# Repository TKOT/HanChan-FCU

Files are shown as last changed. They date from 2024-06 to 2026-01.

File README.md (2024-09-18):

# HanChan-FCU（寒蝉FCU）

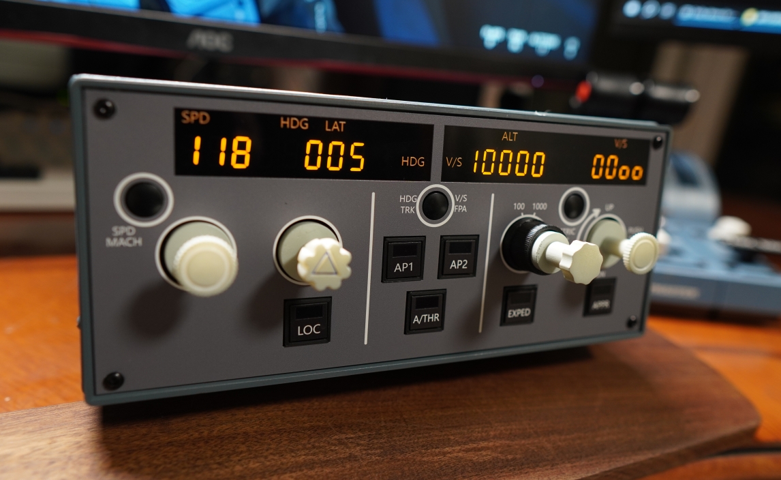
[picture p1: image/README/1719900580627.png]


## 项目简介

HanChan-FCU（寒蝉FCU）这个是基于MobiFlight固件与Arduino mega2560开发板自制的空客Airbus A320的FCU（飞行控制单元），推拉机械结构参考使用了用户@Santi Luib III。

基于mobiflight固件，所以此项目的FCU能支持配置到市面上几乎所有主流的模拟飞行平台和机型，且硬件维护成本较低，采用金属外壳。

本项目是起因是重新游玩“微软模拟飞行2020”，当时市面上无售价合适性价比较高的空客FCU产品（现在已有几个不错产品），而且中文互联网也没有人分享DIY方案。所以就想到要自己DIY一个FCU产品。

整个项目是本人一个人用业余时间完成的，修改迭代了上百个小版本，无偿分享给飞友。

本人做视频与分享知识的一个目的也是希望提升中文社区的一个技术氛围。能增加中文互联网的开源整体环境，每个人互帮互助。

希望大家之后也能发布相关学习经验 来提高中文网上社区环境。

项目整体介绍视频：[点击此文字](https://www.bilibili.com/video/BV154421D7D3/)

硬件制作教程视频：[点击此文字](https://www.bilibili.com/video/BV18z421q7wh)

讨论群：923213555

## 版权控制

本项目禁止其他任何商业行为，**仅供飞友个人DIY使用。**

如有发现有其他商业使用的行为（包括不限于闲鱼淘宝等），将直接闭源，不再更新。

在粉丝建议下加入，如果非要商用：“商用者即同意条款：将营业额60%作为技术费用付给开源作者本人。”

## 第一次使用教程

### 一、刷入固件教程：

#### 1.按图所示选择先选择 Arduino Mega2560 刷入底层固件。

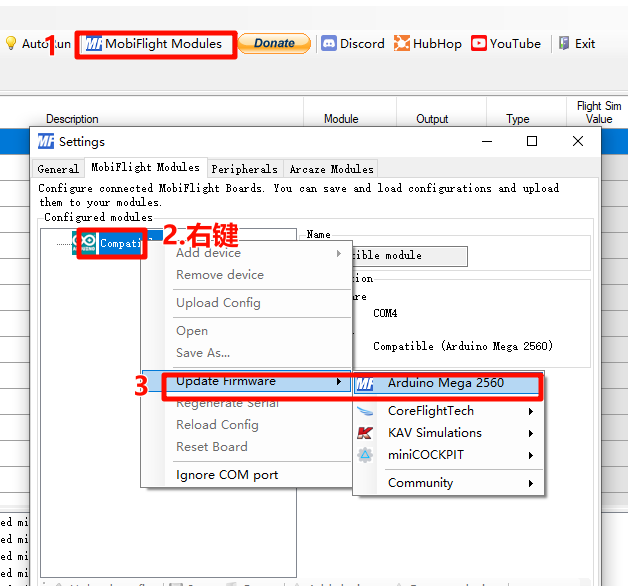
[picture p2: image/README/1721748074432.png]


#### 2.载入固件配置：（固件配置名称 例：HanChan-V1-2-3.mfmc）

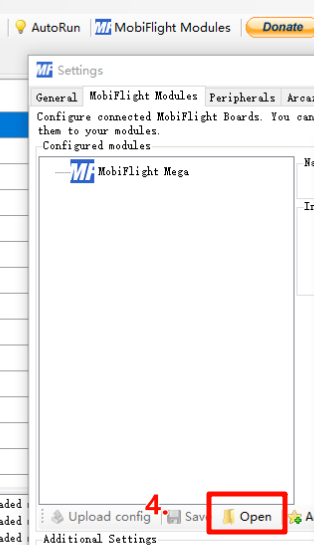
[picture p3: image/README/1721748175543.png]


### 二、加载mobi配置步骤：

1. **先插入FCU到电脑。**
2. **打开mobi软件并 打开配置**。配置名例：**V1.2.3fenixA320.mcc**

   

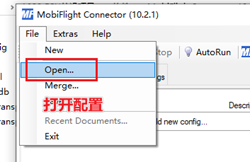
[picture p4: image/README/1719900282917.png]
   

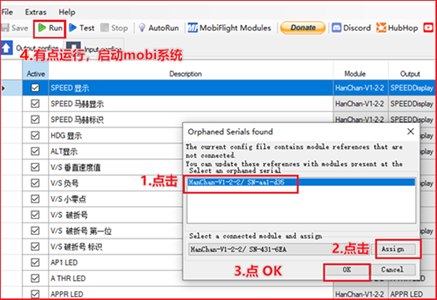
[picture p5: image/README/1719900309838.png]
   
3. **结束配置，以后插入FCU使用点击Run 就可以直接使用FPU了。**

## 项目更新

V1.2.3：
显示模块重置，配置做修改。

V1.2.2：
1.重写了配置文件，完善了功能。
2.面板尺寸修改。减少与金属机箱缝隙。
3.打印面板参考真机样式，小改。

V1.2.1：
1.推拉结构间隙调整，提高手感减小矿量。
2.圆形按钮 卡槽加高深度。按钮突出更合理点。
2.面板UV打印部分做了小修改。

V1.2.0：
1.升级了上面三个圆形按钮的元件选型，继续靠近真机细节。
2.更改了面板布局，整个外面，面板UV打印部分重置重新绘制过了。
3. 3D打印的主体面板，设置设计升级了定位孔，减少胶水粘结部分，改为螺丝连接，更加紧固了。
4.拖拉结构的定位孔进行了细调，用来配合主体面板。

## 支持

如果帮助到大家，欢迎大家捐赠和购买我的配件合集来支持项目的更新与迭代。

闲鱼 直接搜 “寒蝉FCU”或者 “寒蝉唱游”就可以了。

如果有需要配件打包的可以到我闲鱼去看下，先上架了了一个预定包。预定包中的配件除了有各种标准电子原件外，还包涵了市面上没有的各种定制件，包含了12位数码管等，而且有部分喷漆改色打磨服务，还有贴纸面板等。主要是简化了大家的定制的精力。

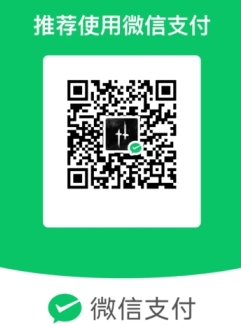
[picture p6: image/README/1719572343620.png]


## 感谢

感谢前期支持迭代，帮忙内测的群友。

@fullofghost   感谢贡献

@紫聪聪         感谢贡献

@Santi Luib III  	模型与机械结构

@L7          		A320真机飞行员 提供真机照片与细节

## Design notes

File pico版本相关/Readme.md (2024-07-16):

# 注意：
1. 买看着像的PICO就行
1. 74HC165按需来，优先小标号（U1），可以根据需要只焊接一个或者两个，不能空过1焊23。74HC595同理。
1. 74HC595配套限流电阻选了220R，可以根据自己选择喜好来换。
1. 增加了亮度控制在14引脚，配置请启用PWM，用于控制所有led亮度，默认不配置就是最大亮度，选配。

# 使用相关
1. 按钮顺序其实建议随便焊接，软件里面挨个调一次比看着配置焊接要方便，灯同理。板子模块配置文件可以加载Pico.mfmc。
2. H1,2,3为按钮
3. H8位编码器左右
4. H9 H10为LED灯
5. H5 H6为74HC165与74HC595与MCU的引脚，用于不会在板子上焊芯片的同学飞线用，不过74HC165本身不带上下拉电阻，不确定是否有问题。
6. H7是LED数码管模块输出引脚。
7. 面板增加了很多LED的位置，用于增加切换显示灯，可以一对一焊接，也可以一组焊在一起。

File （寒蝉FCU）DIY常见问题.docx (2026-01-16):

# 寒蝉FCU 制作DIY常见问题

1. 数码管乱码。

大概率是杜邦线稳定性太差，接触不良导致。可以换更好的硅胶杜邦线，或者直接焊接。

2. 无12位数码管。

可以使用两个8位代替，其中一个去掉四位数码管即可。高度可用排针调整。

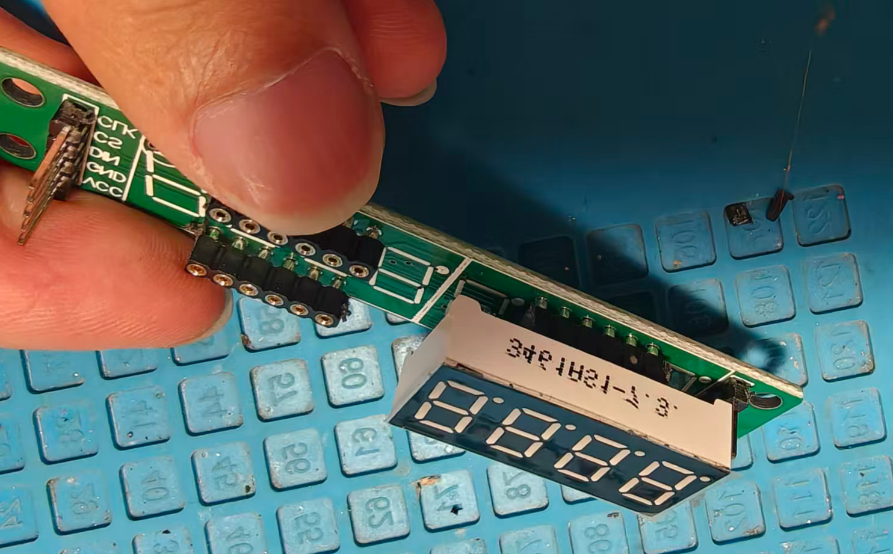
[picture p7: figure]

3. 如何方便的调整数码管模块的方位针脚。

加热焊盘顶出即可。

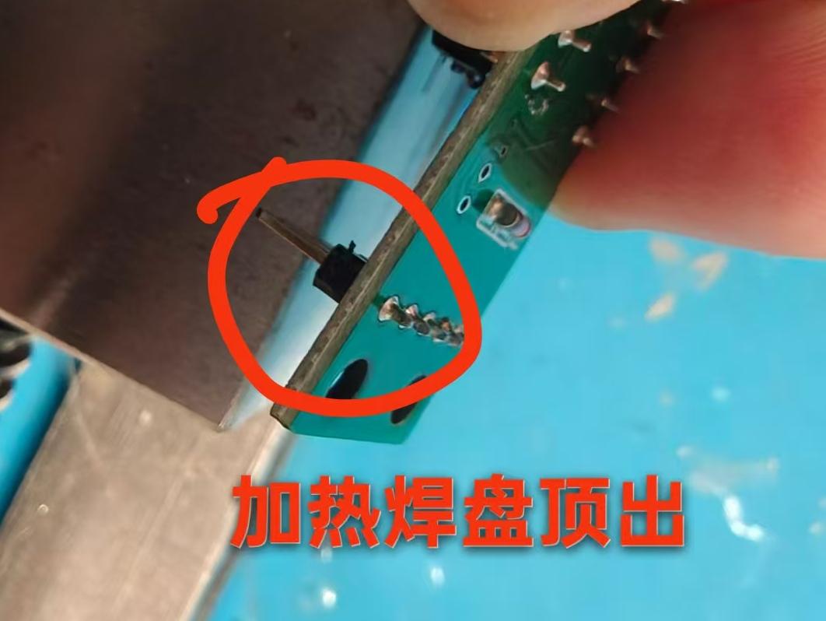
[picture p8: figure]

4. 如何方便调试FCU功能是否正常。

设置中开启log即可

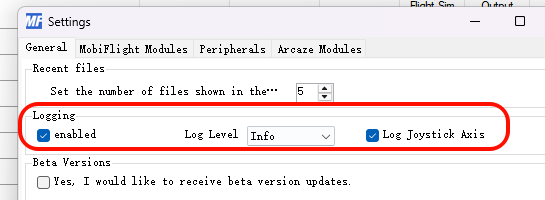
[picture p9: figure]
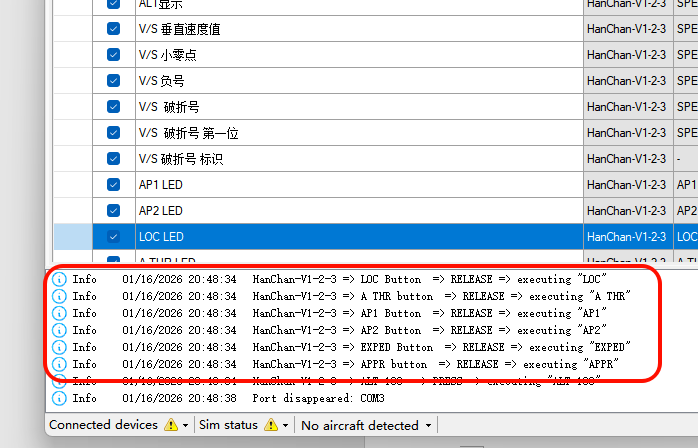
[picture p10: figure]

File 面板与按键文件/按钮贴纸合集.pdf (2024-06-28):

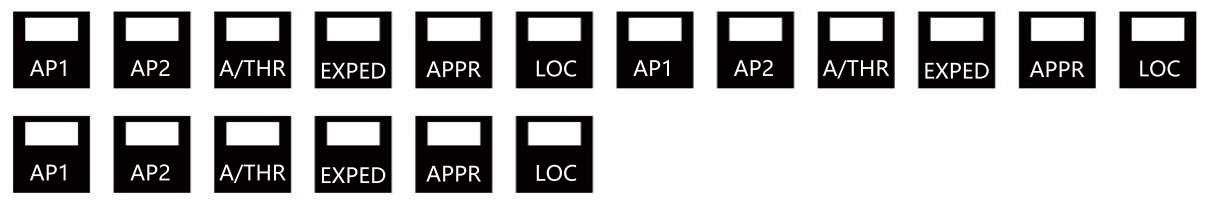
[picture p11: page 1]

AP1 | AP2 | A/THR EXPED | APPR | LOC | AP1 | AP2 | A/THR EXPED | APPR | LOC
AP1 | AP2 | A/THR EXPED | APPR | LOC

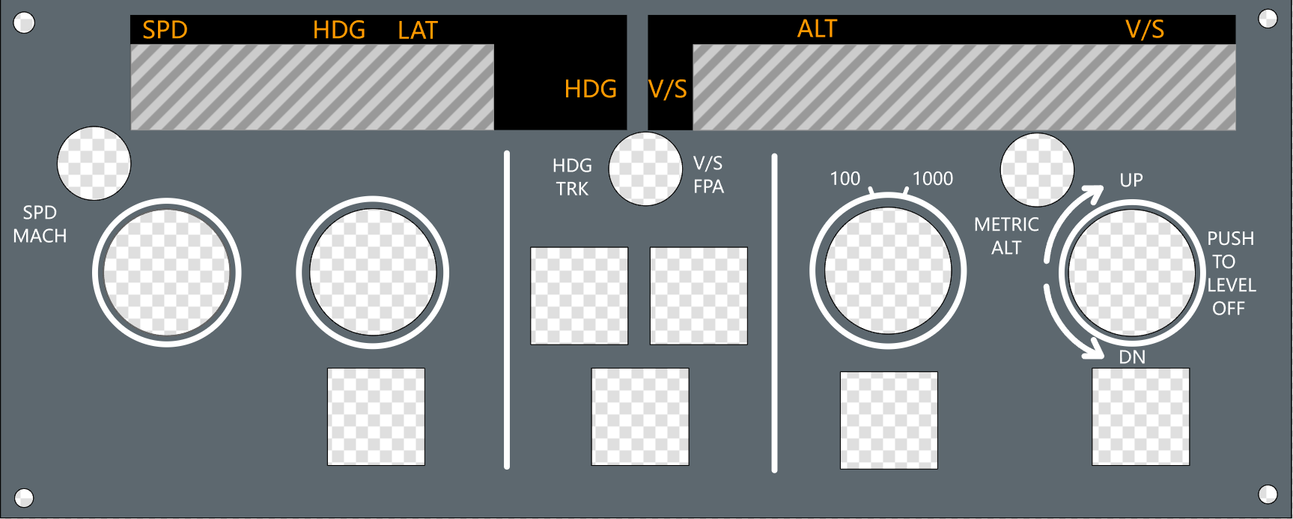
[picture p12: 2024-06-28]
面板与按键文件/前面板.webp

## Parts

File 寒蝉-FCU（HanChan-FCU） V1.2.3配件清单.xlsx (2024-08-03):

寒蝉-FCU（HanChan-FCU） V1.2.3配件清单
视频教程 |  | https://www.bilibili.com/video/BV18z421q7wh
名称 | 规格 | 数量 | 备注
灯光按钮3D打印件 | 灯光上盖 | 6
 | 内壳 | 6
 | 外壳 | 6
高度旋钮3D打印件 | 100-1000 选择 | 1
 | 高度-面板链接件 | 1
 | 高度旋钮外壳 | 1
 | 连杆 | 1
 | 钮子开关座 | 1
 | 钮子拨杆 | 1
其他3D打印件 | 推拉内壳 | 4
 | 推拉外壳 v16 | 3
 | 主板支架 v3 | 1
 | 主面板 | 1 | 219*88mm
 | 航向按钮 圆形版本 | 1
 | 速度按钮 圆形版本 | 2
 | 速度按钮半圆 | 2 | 可选
 | 航向按钮半圆 | 1 | 可选
 | 高度选择旋钮 | 1
按钮 | 12*12*7.3mm方头 | 7
 | 3*6*4.3MM立式插脚白色黑色2脚 | 6
LED发光管 | 3mm绿色 | 6
数码管模块 | 8位数码管模块max7219 led八位 | 3 | 需要自己拆换
杜邦线 | 母对公、母对母等 | 几十 | 粗估
编码器 | ec11 20mm (https://item.taobao.com/item.htm?id=600216770759&_u=r41dfih1381) | 4
钮子开关 | mts-102 | 1
电阻 | 2.2k 直插 | 6
按钮帽 | 轻触开关帽，圆形直径10mm | 3 | 配12*12*7.3mm方头
主板 | Arduino mega2560 | 1
机箱 | 单面配合主面板尺寸219*88mm即可 | 1
灯光印刷贴纸或面板 | 开源定制 | 6
主面板 贴纸或面板 | 开源定制 | 1
螺丝 | M3*8 | 16 | 建议不同长度的配点备用
 | M3*12 | 2
 | M3 螺丝 螺母一套 | 2 | 固定主板

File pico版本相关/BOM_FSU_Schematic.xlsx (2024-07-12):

No. | Quantity | Comment | Designator | Footprint | Value | Manufacturer Part | Manufacturer | Supplier Part | Supplier
1 | 1 | Btn0 | H1 | HDR-TH_16P-P2.54-V-M-R2-C8-S2.54 |  |  |  | C68234
2 | 1 | Btn1 | H2 | HDR-TH_16P-P2.54-V-M-R2-C8-S2.54 |  |  |  | C68234
3 | 1 | Btn2 | H3 | HDR-TH_16P-P2.54-V-M-R2-C8-S2.54 |  |  |  | C68234
4 | 1 | HDR-M_2.54_1x16P | H4 | HDR-TH_16P-P2.54-V-M |  |  |  | C2894939
5 | 1 | LED输出 | H5 | HDR-TH_5P-P2.54-V-M |  | MTP125-1105S1 | MINTRON(明硕) | C358687 | LCSC
6 | 1 | BTN输入 | H6 | HDR-TH_5P-P2.54-V-M |  | MTP125-1105S1 | MINTRON(明硕) | C358687 | LCSC
7 | 1 | Display模块 | H7 | HDR-TH_5P-P2.54-V-M |  | MTP125-1105S1 | MINTRON(明硕) | C358687 | LCSC
8 | 1 | Encoder连接 | H8 | HDR-TH_8P-P2.54-V-F-R2-C4-S2.54-1 |  |  |  | C92271
9 | 2 | HDR-F_2.54_2x8 | H9,H10 | HDR-TH_16P-P2.54-V-F-R2-C8-S2.54-1 |  |  |  | C30734
10 | 2 | M3螺丝 | TP1,TP2 | M3螺丝
11 | 3 | 74HC165D,653 | U1,U2,U3 | SOIC-16_L9.9-W3.9-P1.27-LS6.0-BL |  | 74HC165D,653 | Nexperia(安世) | C5613 | LCSC
12 | 6 | 10K排阻-4D03 | U4,U5,U6,U7,U8,U9 | RES-ARRAY-SMD_8P-L3.2-W1.6-P0.80-BL |  | 10K排阻-4D03 |  | C9900011904 | LCSC
13 | 1 | PICO | U10 | COMM-SMD_L51.0-W21.0-P2.54_SC0916 |  | PICO | Raspberry Pi(树莓派) | C7203002 | LCSC
14 | 4 | 470Ω | U11,U13,U15,U16 | RES-ARRAY-SMD_0603-8P-L3.2-W1.6-BL | 470Ω | 4D03WGJ0471T5E | UNI-ROYAL(厚声) | C25510 | LCSC
15 | 2 | 74HC595 | U12,U14 | SOP-16_L9.9-W3.9-P1.27-LS6.0-BL |  | 74HC595 | GR(国睿) | C18164493 | LCSC

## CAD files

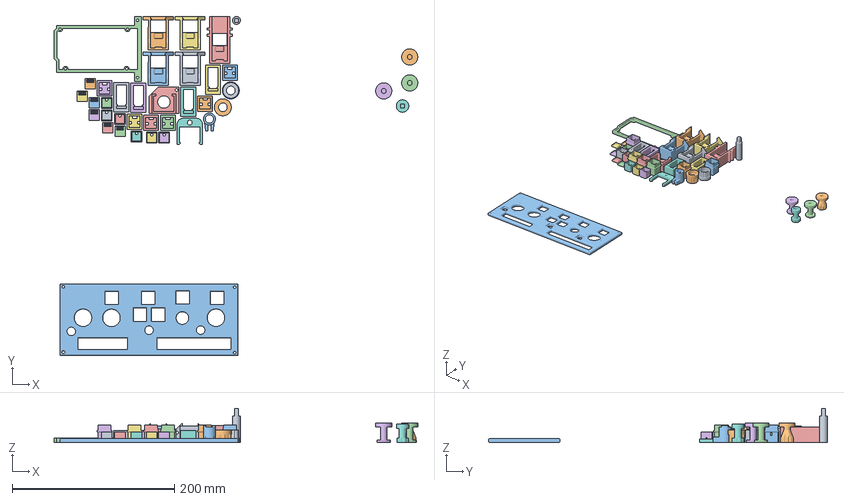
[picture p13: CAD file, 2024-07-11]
3D打印模型/all.3mf
447.9 x 417.5 x 41.9 mm
连杆.stl
航向按钮 圆形版本.stl
主面板.stl
速度按钮 圆形版本.stl x 2
高度旋钮外壳.stl
推拉外壳 v16.stl x 4
高度选择按钮.stl
主板支架 v3.stl
高度-面板链接件.stl
推拉内壳.stl x 4
外壳.stl x 6
钮子开关座.stl
100-1000 选择.stl x 2
钮子拨杆.stl
内壳.stl x 6
灯光按钮上盖 v2.stl x 6

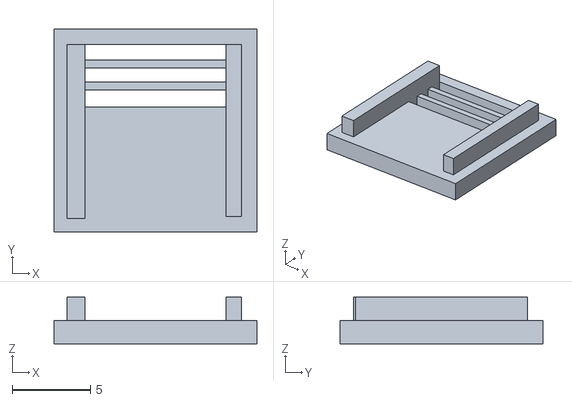
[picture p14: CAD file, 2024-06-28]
3D打印模型/灯光按钮/灯光按钮上盖 v2.stl
13.0 x 13.0 x 3.00

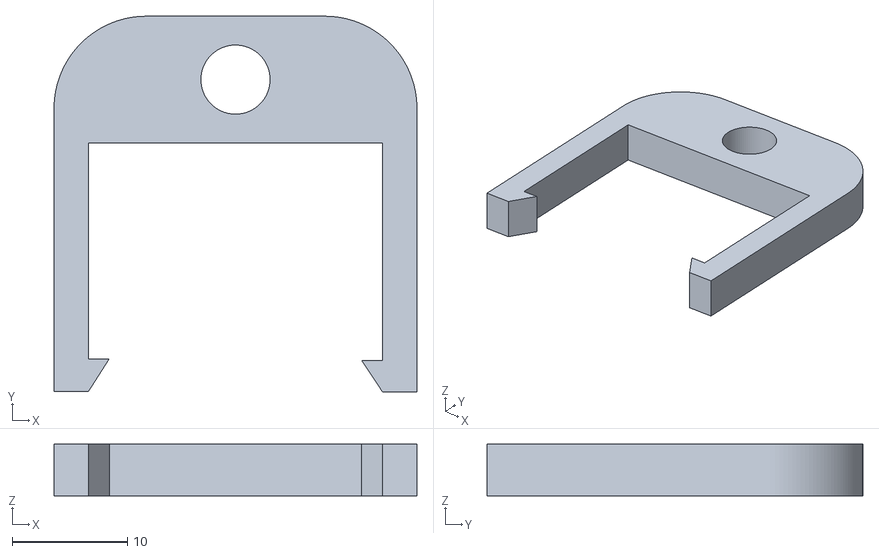
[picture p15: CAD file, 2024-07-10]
3D打印模型/高度旋钮部分/钮子开关座.stl
31.5 x 32.6 x 4.50

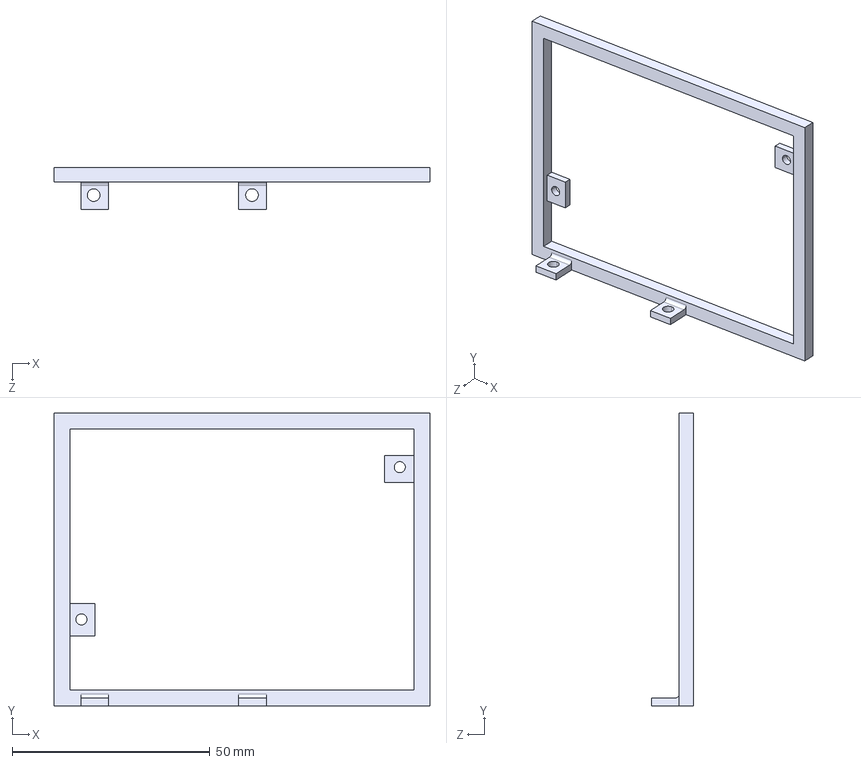
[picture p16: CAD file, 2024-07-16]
pico版本相关/托板.STEP
95.0 x 74.0 x 10.6 mm

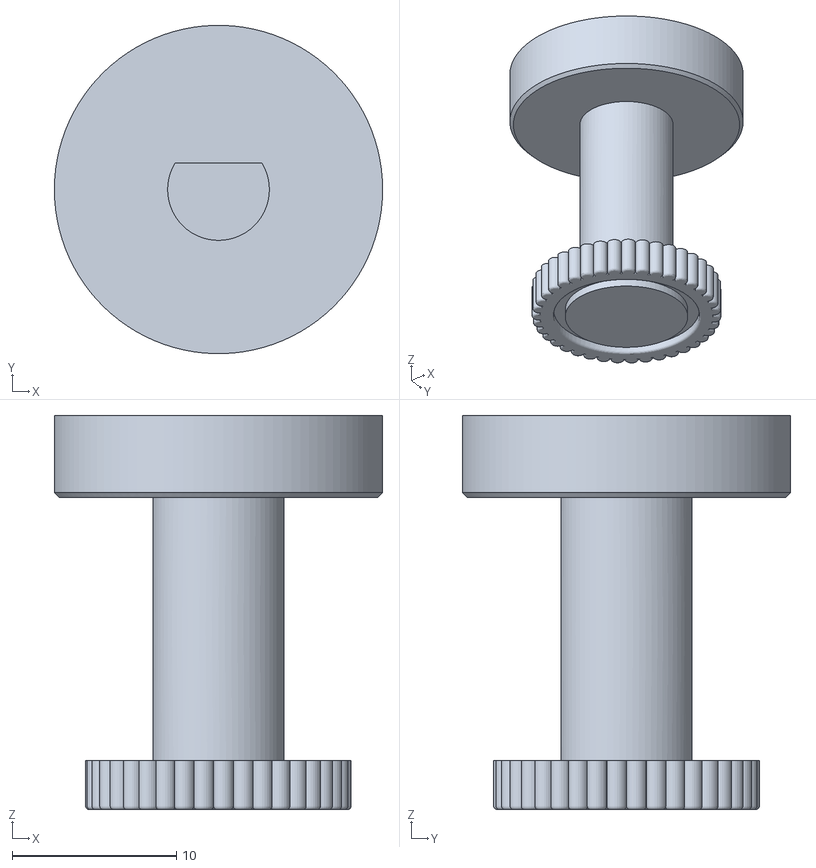
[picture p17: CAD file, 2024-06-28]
3D打印模型/垂直速度 按钮.stl
20.0 x 20.0 x 24.0

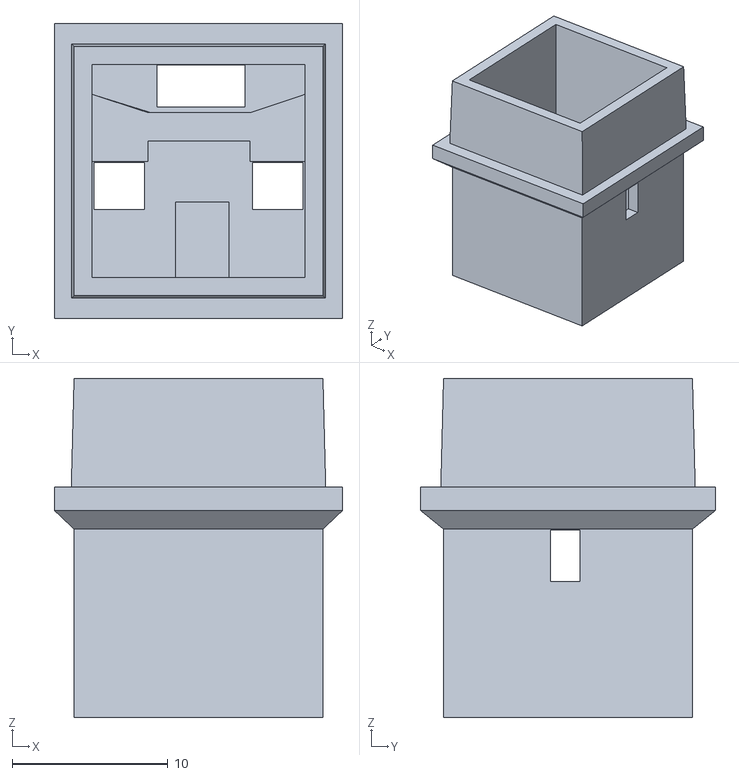
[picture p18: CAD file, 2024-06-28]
3D打印模型/灯光按钮/外壳.stl
18.5 x 18.9 x 21.8

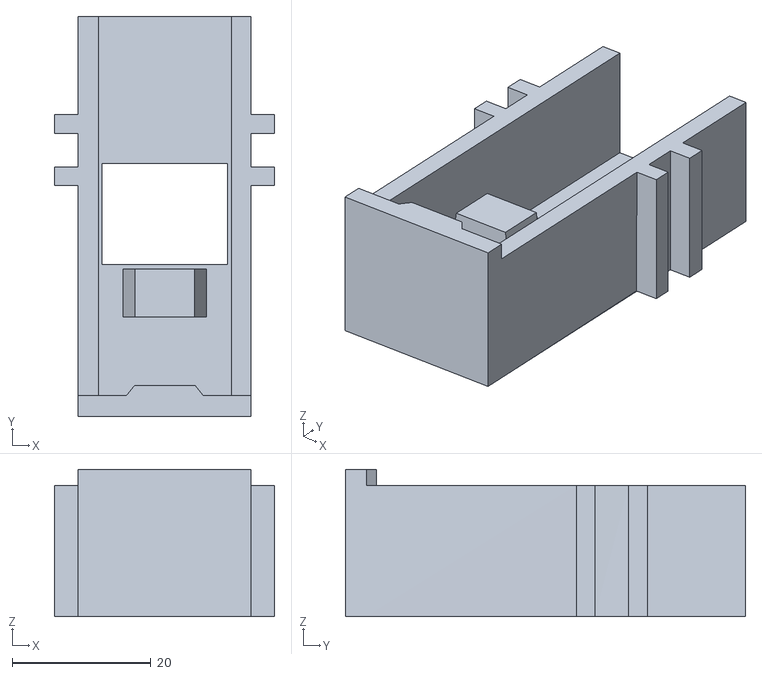
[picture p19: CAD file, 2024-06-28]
3D打印模型/高度旋钮部分/高度旋钮外壳.stl
31.7 x 57.6 x 21.2

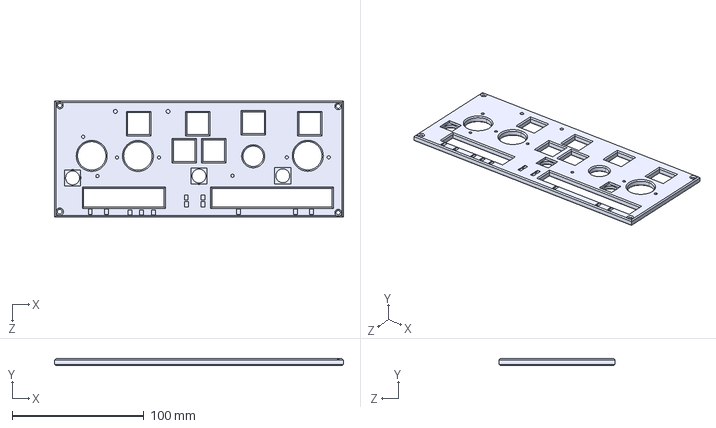
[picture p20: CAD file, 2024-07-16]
pico版本相关/面板.STEP
219.0 x 5.00 x 88.0 mm

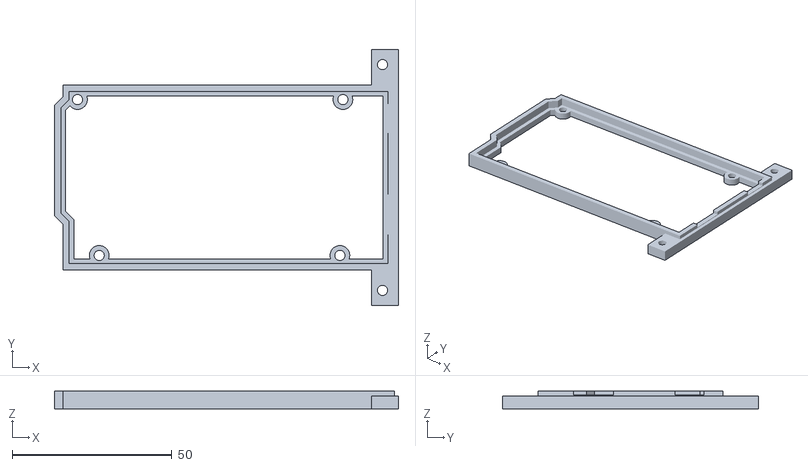
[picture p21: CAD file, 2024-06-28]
3D打印模型/主板支架 v3.stl
107.7 x 80.0 x 5.50

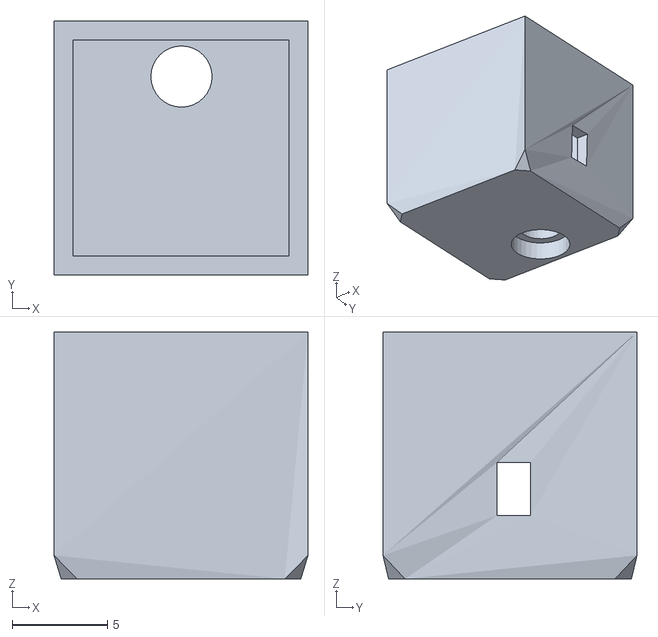
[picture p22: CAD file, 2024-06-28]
3D打印模型/灯光按钮/内壳.stl
13.3 x 13.3 x 13.0

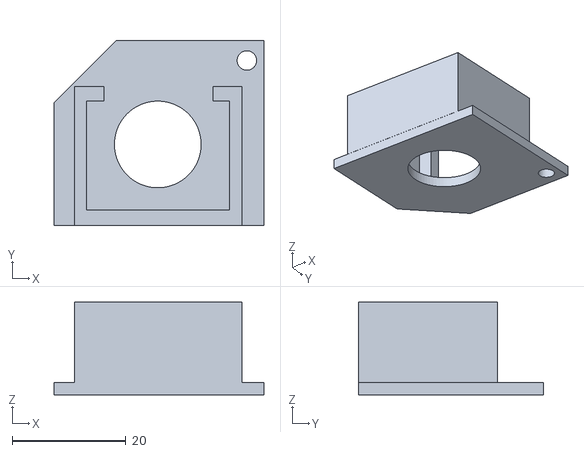
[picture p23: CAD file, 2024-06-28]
3D打印模型/高度旋钮部分/高度-面板链接件.stl
37.0 x 32.6 x 16.4

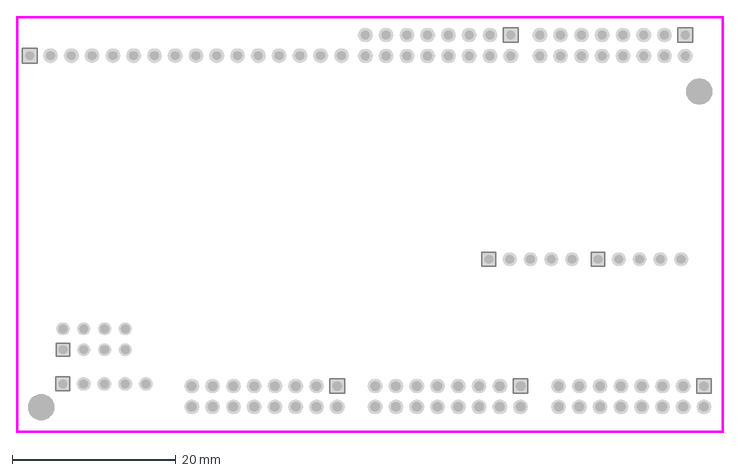
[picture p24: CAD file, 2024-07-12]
pico版本相关/DXF_PCB.dxf
86.5 x 50.9 mm

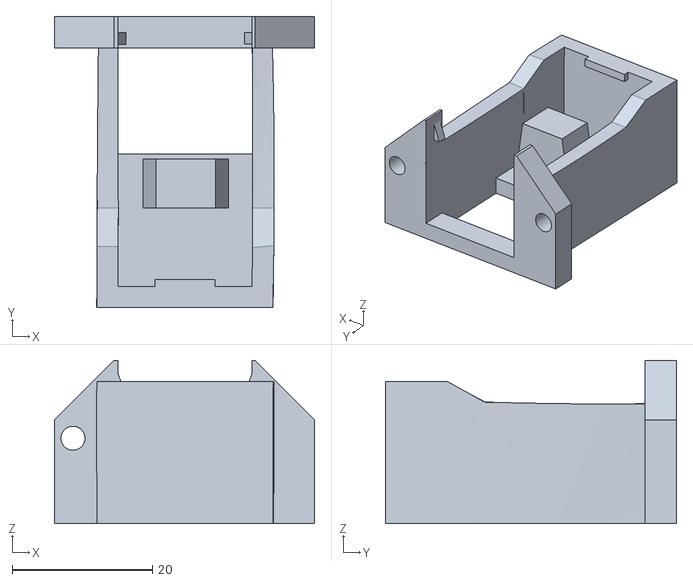
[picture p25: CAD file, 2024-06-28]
3D打印模型/推拉外壳 v16.stl
37.1 x 41.5 x 23.3

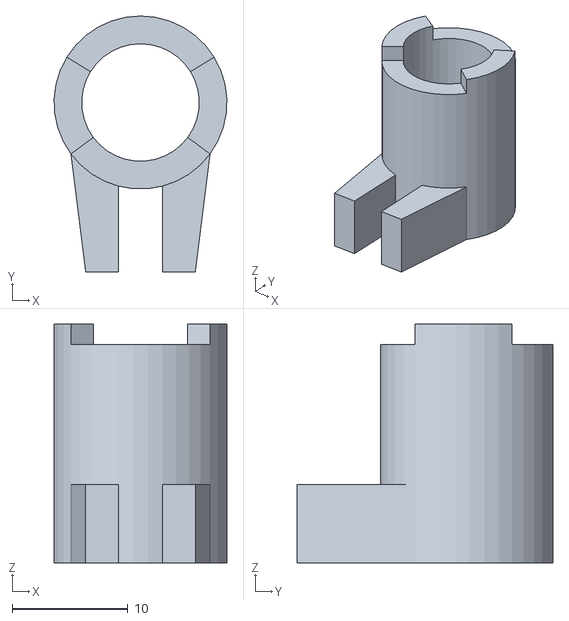
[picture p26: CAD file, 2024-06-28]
3D打印模型/高度旋钮部分/钮子拨杆.stl
14.9 x 22.1 x 20.7

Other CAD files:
面板与按键文件/后面板.dwg
3D打印模型/高度旋钮部分/连杆.stl
3D打印模型/高度选择按钮.stl
3D打印模型/推拉内壳.stl
3D打印模型/主面板.stl
3D打印模型/航向 按钮.stl
3D打印模型/航向按钮 圆形版本.stl
3D打印模型/速度按钮 圆形版本.stl
3D打印模型/高度旋钮部分/100-1000选择旋帽.stl

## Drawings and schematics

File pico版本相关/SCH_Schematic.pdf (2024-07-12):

# DS 10 D0 11 D1 12 D2 13 D3 14 CE# 15 VCC 16

# DS 10 D0 11 D1 12 D2 13 D3 14 CE# 15 VCC 16

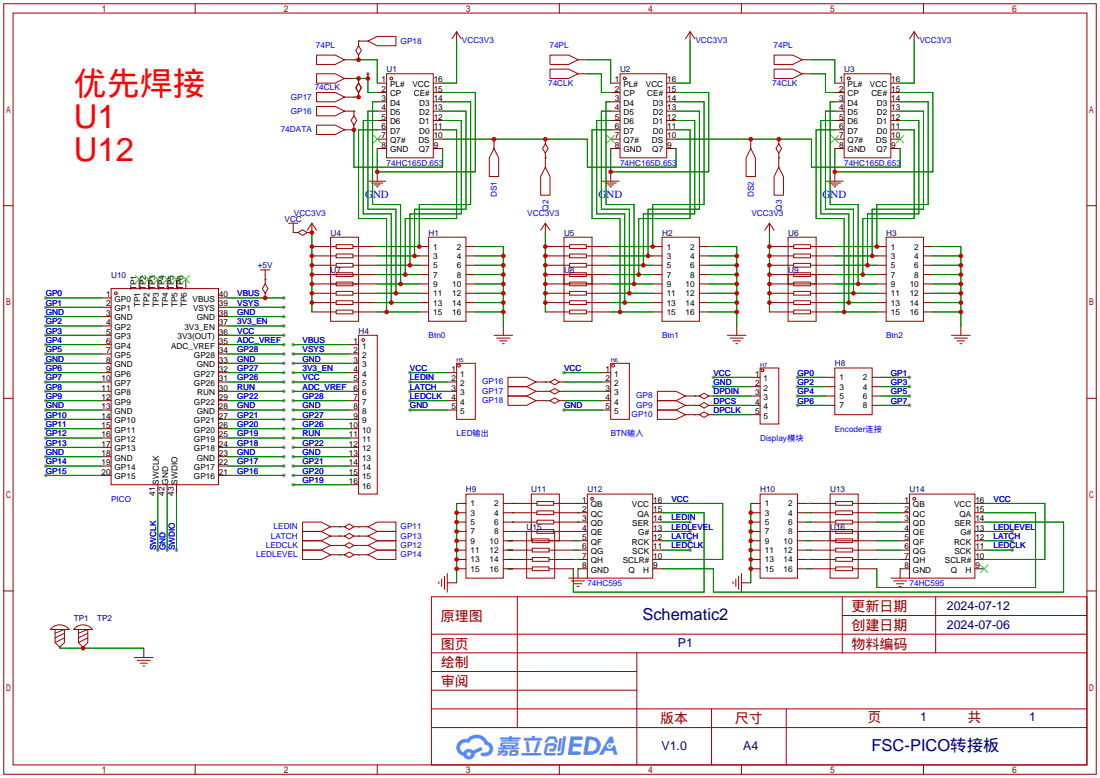
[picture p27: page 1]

SCLR# 10 SCK 11 RCK 12 G# 13 SER 14 QA 15 VCC 16

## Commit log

2024-07-03 Update 寒蝉-FCU（HanChan-FCU） V1.2.3配件清单.xlsx
    [寒蝉-FCU（HanChan-FCU） V1.2.3配件清单.xlsx]
2024-07-10 引入所有模型制作3mf 旋钮设置P/P相互支撑，保证支撑面光洁度
    [all.3mf]
2024-07-11 添加感谢
2024-07-12 增加PICO板子相关支持，比MEGA2560便宜。
    [BOM_FSU_Schematic.xlsx, DXF_PCB.dxf, 元件与pico开发板插接对应表.xlsx]
2024-07-16 增加修改后模型文件
    [托板.STEP, 面板.STEP]
2024-07-23 Update 元件与mega2650开发板插接对应表.xlsx
    更新说明
    [元件与mega2650开发板插接对应表.xlsx]
2024-07-23 新增教程文件
2024-07-29 修改细节
    [元件与mega2560开发板插接对应表.xlsx, 元件与mega2650开发板插接对应表.xlsx, 寒蝉-FCU（HanChan-FCU） V1.2.3配件清单.xlsx]
2024-08-03 配件细节调整
    [100-1000选择旋帽.stl, 元件与mega2560开发板插接对应表.xlsx, 寒蝉-FCU（HanChan-FCU） V1.2.3配件清单.xlsx]
2025-02-06 添加新配置
2026-01-16 常见问题解决方案上传
